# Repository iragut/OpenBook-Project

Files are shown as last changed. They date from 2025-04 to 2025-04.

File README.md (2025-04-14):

# README - OpenBook E-Reader

## Introducere
OpenBook este un e-reader open-source construit în jurul microcontrollerului ESP32-C6, integrând un display e-paper de 7.5 inch, senzori de mediu (BME680), management al bateriei și interfețe precum Wi-Fi și USB-C. Acest document oferă o privire de ansamblu asupra designului hardware, componentelor utilizate și conexiunilor lor.

---

## Diagrama bloc
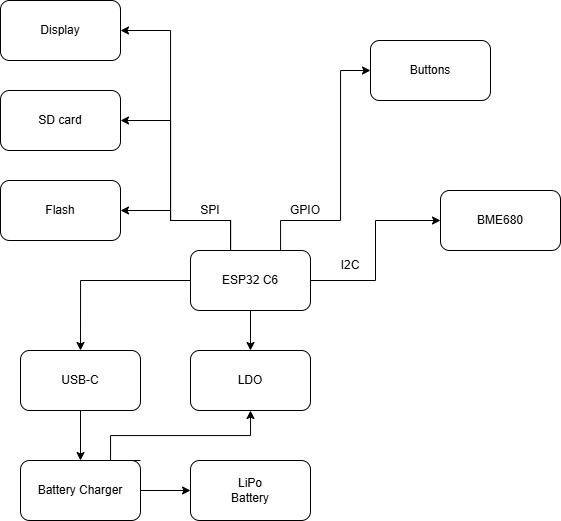
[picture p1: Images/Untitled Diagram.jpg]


## Bill of Materials (BOM)
Tabelul de mai jos include componentele principale din BOM-ul furnizat, cu link-uri către Mouser și datasheet-uri unde sunt disponibile.

| **Componentă** | **Valoare/Part Number** | **Descriere** | **Furnizor (Mouser)** | **Datasheet** |
|---|---|---|---|---|
| U2 | ESP32-C6-WROOM-1-N8 | Microcontroller Wi-Fi 6, Bluetooth 5 | [Mouser](https://eu.mouser.com/ProductDetail/Espressif-Systems/ESP32-C6-WROOM-1-N8)  | [Datasheet](https://www.espressif.com/sites/default/files/documentation/esp32-c6-wroom-1_datasheet_en.pdf) |
| U1 | W25Q512JVEIQ | 512Mb Flash SPI | [Mouser](https://eu.mouser.com/ProductDetail/Winbond/W25Q512JVEIQ) | [Datasheet](https://www.winbond.com/resource-files/W25Q512JV%20RevD%2004082020.pdf) |
| S | BME680 | Senzor temperatură, umiditate, presiune | [Mouser](https://eu.mouser.com/ProductDetail/Bosch-Sensortec/BME680) | [Datasheet](https://www.bosch-sensortec.com/media/boschsensortec/downloads/datasheets/bst-bme680-ds001.pdf) |
| U3 | DS3231SN# | RTC I2C | [Mouser](https://eu.mouser.com/ProductDetail/Analog-Devices/DS3231SN) | [Datasheet](https://www.analog.com/media/en/technical-documentation/data-sheets/DS3231.pdf) |
| U4 | MAX17048G+T10 | Fuel Gauge I2C | [Mouser](https://eu.mouser.com/ProductDetail/Analog-Devices/MAX17048G+T10) | [Datasheet](https://www.analog.com/media/en/technical-documentation/data-sheets/MAX17048.pdf) |
| U5 | MCP73831T-2ACI/OT | Încărcător Li-Po USB-C | [Mouser](https://eu.mouser.com/ProductDetail/Microchip-Technology/MCP73831T-2ACI-OT) | [Datasheet](https://ww1.microchip.com/downloads/en/DeviceDoc/20001984G.pdf) |
| J2 | USB4110-GF-A | Conector USB-C | [Mouser](https://eu.mouser.com/ProductDetail/GCT/USB4110-GF-A) | [Datasheet](https://www.gct.co/connector/usb4110) |
| BOOT_BUTTON | EVQPUJ02K | Buton tactil | [Mouser](https://eu.mouser.com/ProductDetail/Panasonic/EVQ-PUJ02K) | [Datasheet](https://www.panasonic.com/global/industrial-components/switches/light-touch/evqpuj02k.pdf) |
| C3 | 100uF TANT (F910J107MBAAJ6) | Condensator polarizat | [Mouser](https://eu.mouser.com/ProductDetail/KYOCERA-AVX/F910J107MBAAJ6) | [Datasheet](https://www.kyocera-avx.com/products/tantalum/) |
| IC4 | XC6220A331MR-G | LDO Regulator | [Mouser](https://eu.mouser.com/ProductDetail/Torex/XC6220A331MR-G) | [Datasheet](https://www.torexsemi.com/file/xc6220/XC6220.pdf) |

---

## Funcționalitate Hardware

### Microcontroller ESP32-C6-WROOM-1-N8
- **Rol**: Procesare centrală, conectivitate Wi-Fi 6 și Bluetooth 5, control al perifericelor.
- **Interfețe**:
  - SPI: Display e-paper, Flash (W25Q512JVEIQ), Micro SD.
  - I2C: BME680, MAX17048, DS3231.
  - GPIO: Butoane, LED, pini de control display.
  - UART: Debugging și extensii.
- **Specificații**: 160MHz, 512KB SRAM, 8MB Flash integrat.

### Display E-Paper
- **Specificații**: 7.5 inch, 800x480, contrast 8:1, SPI 4-wire.
- **Conexiune**: MOSI, MISO, SCK, CS + DC, RST, BUSY.
- **Consum**: <50mA în refresh, aproape 0 în standby.

### Senzor BME680
- **Funcție**: Măsoară temperatura (±1°C), umiditatea (±3%), presiunea (±1 hPa) și calitatea aerului (eCO2, TVOC).
- **Interfață**: I2C la 400kHz.
- **Consum**: <1mA activ, <1µA în sleep.

### Management Baterie
- **Baterie**: 2500mAh Li-Po, 3.7V.
- **Încărcare**: MCP73831 prin USB-C (1A max).
- **Monitorizare**: MAX17048 prin I2C.
- **Consum**: <50µA în deep sleep.

### Butoane
- Trei butoane tactile (Panasonic EVQPUJ02K) pentru navigare, cu rezistențe pull-up de 10K.

### USB-C
- **Rol**: Încărcare (5V/1A) și transfer date (USB 2.0).
- **Protecție**: ESD diodes (USBLC6-2SC6Y).

### Calcul Consum Energie
- **Activ (Wi-Fi + Display Refresh)**: ~150mA.
- **Citire (Display static)**: ~10mA.
- **Deep Sleep**: <50µA.
- **Autonomie estimată**: ~1 săptămână (2500mAh / 10mA medie = ~250 ore).

---

## Pini ESP32-C6 Utilizați

| **Pin ESP32-C6** | **Funcție** | **Componentă** | **Motiv** |
|---|---|---|---|
| GPIO0 | BOOT_BUTTON | Buton | Detectare mod boot la pornire |
| GPIO1 | RESET_BUTTON | Buton | Reset manual al dispozitivului |
| GPIO2 | CHANGE_BUTTON | Buton | Navigare meniuri |
| GPIO3 | EPD_CS | Display E-Paper | Chip Select pentru SPI |
| GPIO4 | EPD_DC | Display E-Paper | Data/Command control |
| GPIO5 | EPD_RST | Display E-Paper | Reset display |
| GPIO6 | EPD_BUSY | Display E-Paper | Detectare stare refresh |
| GPIO7 | SPI_MOSI | Display, Flash, SD | Master Out Slave In (SPI) |
| GPIO8 | SPI_MISO | Display, Flash, SD | Master In Slave Out (SPI) |
| GPIO9 | SPI_SCK | Display, Flash, SD | Clock SPI |
| GPIO10 | FLASH_CS | W25Q512JVEIQ | Chip Select pentru Flash |
| GPIO11 | SD_CS | Micro SD | Chip Select pentru SD |
| GPIO12 | I2C_SDA | BME680, MAX17048, DS3231 | Date I2C |
| GPIO13 | I2C_SCL | BME680, MAX17048, DS3231 | Clock I2C |
| GPIO14 | CHG_LED | LED | Indicare status încărcare |
| GPIO15 | UART_TX | Debugging | Transmitere date serial |
| GPIO16 | UART_RX | Debugging | Recepție date serial |
| GPIO17 | USB_D+ | USB-C | Linie date USB pozitivă |
| GPIO18 | USB_D- | USB-C | Linie date USB negativă |

**Notă**: Pinii sunt alocați conform specificațiilor ESP32-C6 și cerințelor ERD/PRD. Unii pini pot fi multifuncționali (ex. GPIO/SPI).

---

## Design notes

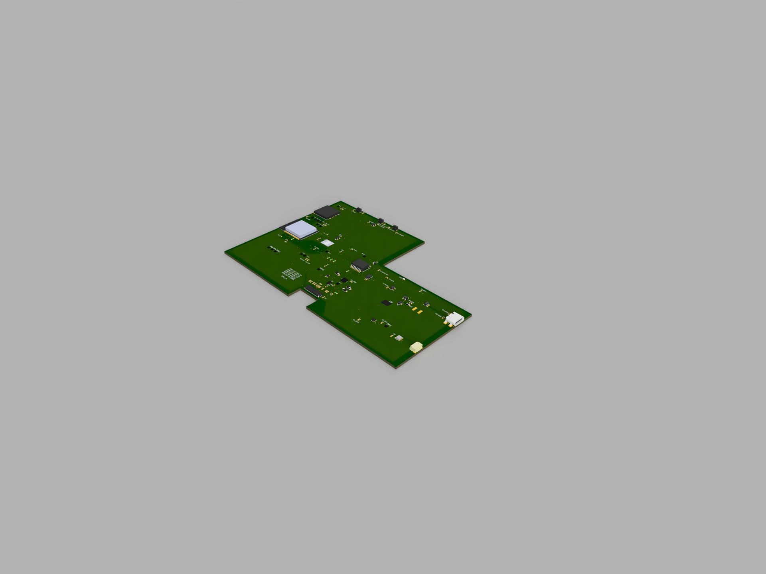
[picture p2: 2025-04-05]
Images/pcb.JPEG

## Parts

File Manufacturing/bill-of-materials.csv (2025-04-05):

Qty | Value | Device | Package | Parts | Description | ARROW_PART_NUMBER | ARROW_PRICE-STOCK | AVAILABILITY | CENTROID_NOT_SPECIFIED | CHECK_PRICES | COPYRIGHT | DATASHEET | DESCRIPTION | DIGIKEY_DESCRIPTION | DIGIKEY_PART_NUMBER | HEIGHT | LEAD_FREE | MANUFACTURER_NAME | MANUFACTURER_PART_NUMBER | MF | MFR_NAME | MOUSER_PART_NUMBER | MOUSER_PRICE-STOCK | MOUSER_TESTING_PART_NUMBER | MOUSER_TESTING_PRICE-STOCK | MP | MPN | PACKAGE | POPULARITY | PREFIX | PRICE | PROD_ID | PURCHASE-URL | ROHS | SNAPEDA_LINK | SPICEMODEL | SPICEPREFIX | TEMPERATURE_RANGE_HIGH | TEMPERATURE_RANGE_LOW | TP_SIGNAL_NAME | VALUE
1 |  | ADAFRUIT_LEDCHIP-LED0603 | ADAFRUIT_CHIP-LED0603 | LED1 | LED
1 |  | SJ | SJ | SJ1 | SMD solder JUMPER |  |  |  |  |  |  |  |  |  |  |  |  |  |  |  |  |  |  |  |  |  |  |  | 3
1 | 0.1uF/50V | ESP32_WROVER_EAGLE-LTSPICE_CC0402 | ESP32_WROVER_EAGLE-LTSPICE_C0402 | EPD_C5 | CAPACITOR, European symbol |  |  |  |  |  |  |  |  |  |  |  |  |  |  |  |  |  |  |  |  |  |  |  |  |  |  |  |  |  |  | NONE | C
1 | 0.47 | ESP32_WROVER_EAGLE-LTSPICE_RR0402 | ESP32_WROVER_EAGLE-LTSPICE_R0402 | R6 | RESISTOR, European symbol |  |  |  |  |  |  |  |  |  |  |  |  |  |  |  |  |  |  |  |  |  |  |  |  |  |  |  |  |  |  | NONE | R
1 | 100k | ESP32_WROVER_EAGLE-LTSPICE_RR0402 | ESP32_WROVER_EAGLE-LTSPICE_R0402 | R1 | RESISTOR, European symbol |  |  |  |  |  |  |  |  |  |  |  |  |  |  |  |  |  |  |  |  |  |  |  |  |  |  |  |  |  |  | NONE | R
8 | 100nF | ESP32_WROVER_EAGLE-LTSPICE_CC0402 | ESP32_WROVER_EAGLE-LTSPICE_C0402 | C1, C2, C4_USB, C5_USB2, C8, COND_BOOT, COND_CHANGE, C_DELAY | CAPACITOR, European symbol |  |  |  |  |  |  |  |  |  |  |  |  |  |  |  |  |  |  |  |  |  |  |  |  |  |  |  |  |  |  | NONE | C
1 | 100uF TANT | RCL_CPOL-EUCT3528 | RCL_CT3528 | C3 | POLARIZED CAPACITOR, European symbol |  |  |  |  |  |  |  |  |  |  |  |  |  |  |  |  |  |  |  |  |  |  |  | 0 |  |  |  |  |  |  |  | C
15 | 10K | ESP32_WROVER_EAGLE-LTSPICE_RR0402 | ESP32_WROVER_EAGLE-LTSPICE_R0402 | R1_PINH1, R2_PINH1, R5, R8, R9, R10, R11, R12, R13, R14, R15, R16, R_BOOT, R_CHANGE, R_RESET | RESISTOR, European symbol |  |  |  |  |  |  |  |  |  |  |  |  |  |  |  |  |  |  |  |  |  |  |  |  |  |  |  |  |  |  | NONE | R
1 | 10k | ESP32_WROVER_EAGLE-LTSPICE_RR0402 | ESP32_WROVER_EAGLE-LTSPICE_R0402 | R7 | RESISTOR, European symbol |  |  |  |  |  |  |  |  |  |  |  |  |  |  |  |  |  |  |  |  |  |  |  |  |  |  |  |  |  |  | NONE | R
1 | 112A-TAAR-R03_ATTEND | 112A-TAAR-R03_ATTEND | 112ATAARR03ATTEND | J2 | Micro SD Card Socket, Push-Push Type, Top Mount, SMT, H=1.83mm, 10u |  |  |  |  |  |  |  | Micro SD Card Socket | Push-Push Type | Top Mount | SMT | H=1.83mm | 10u |  |  | 1.9mm |  | ATTEND | 112A-TAAR-R03 ATTEND
1 | 15 | ESP32_WROVER_EAGLE-LTSPICE_RR0402 | ESP32_WROVER_EAGLE-LTSPICE_R0402 | R_CAPACITOR | RESISTOR, European symbol |  |  |  |  |  |  |  |  |  |  |  |  |  |  |  |  |  |  |  |  |  |  |  |  |  |  |  |  |  |  | NONE | R
1 | 1uF | ESP32_WROVER_EAGLE-LTSPICE_CC0402 | ESP32_WROVER_EAGLE-LTSPICE_C0402 | COND_RESET | CAPACITOR, European symbol |  |  |  |  |  |  |  |  |  |  |  |  |  |  |  |  |  |  |  |  |  |  |  |  |  |  |  |  |  |  | NONE | C
9 | 1uF/50V | ESP32_WROVER_EAGLE-LTSPICE_CC0402 | ESP32_WROVER_EAGLE-LTSPICE_C0402 | EPD_C1, EPD_C2, EPD_C6, EPD_C7, EPD_C8, EPD_C9, EPD_C10, EPD_C11, EPD_C12 | CAPACITOR, European symbol |  |  |  |  |  |  |  |  |  |  |  |  |  |  |  |  |  |  |  |  |  |  |  |  |  |  |  |  |  |  | NONE | C
1 | 2.2 | ESP32_WROVER_EAGLE-LTSPICE_RR0402 | ESP32_WROVER_EAGLE-LTSPICE_R0402 | R4 | RESISTOR, European symbol |  |  |  |  |  |  |  |  |  |  |  |  |  |  |  |  |  |  |  |  |  |  |  |  |  |  |  |  |  |  | NONE | R
1 | 200 | ESP32_WROVER_EAGLE-LTSPICE_RR0402 | ESP32_WROVER_EAGLE-LTSPICE_R0402 | R1_BAT | RESISTOR, European symbol |  |  |  |  |  |  |  |  |  |  |  |  |  |  |  |  |  |  |  |  |  |  |  |  |  |  |  |  |  |  | NONE | R
2 | 20V/4.2A/52mO/1.4W | ESP32_WROVER_SPARKFUN-DISCRETESEMI_MOSFET_PCH-DMG2305UX-7 | ESP32_WROVER_SPARKFUN-DISCRETESEMI_SOT23-3 | Q1, Q3 | P-channel MOSFETs |  |  |  |  |  |  |  |  |  |  |  |  |  |  |  |  |  |  |  |  |  |  |  |  |  |  | TRAN-14388 |  |  |  |  |  |  |  |  | 20V/4.2A/52mO/1.4W
1 | 2k | ESP32_WROVER_EAGLE-LTSPICE_RR0402 | ESP32_WROVER_EAGLE-LTSPICE_R0402 | R2_BAT | RESISTOR, European symbol |  |  |  |  |  |  |  |  |  |  |  |  |  |  |  |  |  |  |  |  |  |  |  |  |  |  |  |  |  |  | NONE | R
7 | 4.7uF | ESP32_WROVER_EAGLE-LTSPICE_CC0402 | ESP32_WROVER_EAGLE-LTSPICE_C0402 | C1_BAT, C1_BAT1, C1_BAT2, C2_BAT, C5_USB, C5_USB3, C5_USB4 | CAPACITOR, European symbol |  |  |  |  |  |  |  |  |  |  |  |  |  |  |  |  |  |  |  |  |  |  |  |  |  |  |  |  |  |  | NONE | C
2 | 5k1 | ESP32_WROVER_EAGLE-LTSPICE_RR0402 | ESP32_WROVER_EAGLE-LTSPICE_R0402 | R2-USB1, R2-USB2 | RESISTOR, European symbol |  |  |  |  |  |  |  |  |  |  |  |  |  |  |  |  |  |  |  |  |  |  |  |  |  |  |  |  |  |  | NONE | R
1 | 68uH | 744043680IND_4828-WE-TPC_WRE | IND_4828-WE-TPC_WRE | L1 |  |  |  |  |  |  | Copyright (C) 2024 Ultra Librarian. All rights reserved. |  |  |  |  |  |  |  | 744043680 |  | Wurth Electronics
1 | BD5229G-TR | BD5229G-TR | SOT95P280X125-5N | IC3 | Voltage Detector with Adjustable Delay Time: CMOS processes are utilized to develop high precision, low current consumption CMOS reset ICs that allow arbitrary setting of the delay time. The extensive lineup includes both Nch Open Drain and CMOS output types in a wide range of detection voltages (from 2.3V to 6.0V, in 0.1V steps), enabling selection of the ideal solution based on customer requirements. In addition, the entire series is of course both lead-free and RoHS-compliant. |  |  |  |  |  |  |  | Voltage Detector with Adjustable Delay Time: CMOS processes are utilized to develop high precision | low current consumption CMOS reset ICs that allow arbitrary setting of the delay time. The extensive lineup includes both Nch Open Drain and CMOS output types in a wide range of detection voltages (from 2.3V to 6.0V | in 0.1V steps) | enabling selection of the ideal solution based on customer requirements. In addition | the entire series is of course both lead-free and RoHS-compliant. |  |  | 1.25mm |  | ROHM Semiconductor | BD5229G-TR |  |  | 755-BD5229G-TR | https://www.mouser.co.uk/ProductDetail/ROHM-Semiconductor/BD5229G-TR?qs=4kLU8WoGk0vvnhrrYwdszw%3D%3D
1 | BME680 | ESP32_WROVER_BME680_BME680 | ESP32_WROVER_BME680_PSON80P300X300X100-8N | U3 | Integrated Environmental Unit |  |  | Unavailable |  |  |  |  | Integrated Environmental Unit |  |  |  |  |  |  | Bosch Sensortec |  |  |  |  |  | BME680 |  | LGA-8 Bosch Tools |  |  | None
2 | BUTTON_CUSYOMV1 | BUTTON_CUSYOMV1 | MYBUTTON | BOOT_BUTTON, RESET_BUTTON
1 | CHANGE_BUTTON | BUTTON_CUSYOMV1 | MYBUTTON | CHANGE_BUTTON
1 | CPH3225A | CPH3225A | CAPCP3225X100N | C7 | Cap 0.011F 3.3V 1210 Flat Check availability |  |  | Not in stock |  | https://www.snapeda.com/parts/CPH3225A/Seiko+Instruments/view-part/?ref=eda |  |  | 11 mF (EDLC) Supercapacitor 3.3 V 1210 (3225 Metric) - - |  |  |  |  |  |  | Seiko Instruments |  |  |  |  |  | CPH3225A |  | 1210 Seiko |  |  | None |  | https://www.snapeda.com/api/url_track_click_mouser/?unipart_id=562593&manufacturer=Seiko Instruments&part_name=CPH3225A&search_term=None |  | https://www.snapeda.com/parts/CPH3225A/Seiko+Instruments/view-part/?ref=snap
1 | DS3231SN# | DS3231SN# | SOIC127P1032X265-16N | U5 | Real Time Clock Serial 16-Pin SOIC W T/R Check availability |  |  | In Stock |  | https://www.snapeda.com/parts/DS3231SN%23/Analog+Devices/view-part/?ref=eda |  |  | Extremely Accurate I²C-Integrated RTC/TCXO/Crystal |  |  |  |  |  |  | Analog Devices |  |  |  |  |  | DS3231SN# |  | SOIC-16 Maxim |  |  | None |  | https://www.snapeda.com/api/url_track_click_mouser/?unipart_id=99048&manufacturer=Analog Devices&part_name=DS3231SN#&search_term=None |  | https://www.snapeda.com/parts/DS3231SN%23/Analog+Devices/view-part/?ref=snap
1 | ESP32-C6-WROOM-1-N8 | ESP32-C6-WROOM-1-N8 | XCVR_ESP32-C6-WROOM-1-N8 | U2 | Check availability |  |  | In Stock |  | https://www.snapeda.com/parts/ESP32-C6-WROOM-1-N8/Espressif+Systems/view-part/?ref=eda |  |  | Multiprotocol Modules ESP32-C6 module | Wi-Fi 6 in 2.4 GHz band | Bluetooth 5 | Zigbee 3.0 and Thread. ESP34-WROOM Compatible - ENGINEERING SAMPLE |  |  |  |  |  |  | Espressif Systems |  |  |  |  |  | ESP32-C6-WROOM-1-N8 |  | None |  |  | None |  |  |  | https://www.snapeda.com/parts/ESP32-C6-WROOM-1-N8/Espressif+Systems/view-part/?ref=snap
1 | ESP32C6_VARISTORCN1812 | ESP32C6_VARISTORCN1812 | ESP32C6_VARISTOR_CT/CN1812 | PFMF.050.1 | VARISTOR |  |  |  |  |  |  |  |  |  |  |  |  |  |  |  |  |  |  |  |  |  |  |  | 0
2 | ESP32_WROVER_AVX---SD0805S020S1R0_AVX_SD0805S020S1R0_0_0AVX_SD0805S020S1R0_0_0 | ESP32_WROVER_AVX---SD0805S020S1R0_AVX_SD0805S020S1R0_0_0AVX_SD0805S020S1R0_0_0 | ESP32_WROVER_AVX---SD0805S020S1R0_AVX_SD0805S020S1R0_0 | D2, D6 | Schottky Barrier Rectifier Diode |  |  |  | No |  |  | http://datasheets.avx.com/schottky.pdf |  | DIODE SCHOTTKY 20V 1A 0805 | 478-7800-1-ND |  | yes |  |  | AVX |  | 581-SD0805S020S1R0 |  |  |  |  |  | 0805 (2012 metric) |  | D |  |  |  | yes |  |  |  | +125°C | -55°C
1 | FH34SRJ-24S-0.5SH_99_ | FH34SRJ-24S-0.5SH_99_ | FH34SRJ24S05SH99 | J3 | (0.50mm) Surface Mount, Right Angle |  |  |  |  |  |  |  | 24 Position FFC | FPC Connector Contacts | (0.50mm) Surface Mount | Right Angle |  |  | 1.1mm |  | Hirose | FH34SRJ-24S-0.5SH(99) |  |  | 798-FH34SRJ24S05SH99 | https://www.mouser.co.uk/ProductDetail/Hirose-Connector/FH34SRJ-24S-0.5SH99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
1 | MAX17048G+T10 | MAX17048G+T10 | SON50P200X200X80-9N | U4 | Check availability |  |  | In Stock |  | https://www.snapeda.com/parts/MAX17048G+T10/Analog+Devices/view-part/?ref=eda |  |  | 3µA 1-Cell/2-Cell Fuel Gauge with ModelGauge |  |  |  |  |  |  | Analog Devices |  |  |  |  |  | MAX17048G+T10 |  | TDFN-8 Maxim |  |  | None |  | https://www.snapeda.com/api/url_track_click_mouser/?unipart_id=329239&manufacturer=Analog Devices&part_name=MAX17048G+T10&search_term=None |  | https://www.snapeda.com/parts/MAX17048G+T10/Analog+Devices/view-part/?ref=snap
3 | MBR0530 | MBR0530 | SOD3716X135N | D3, D4, D5 | ON SEMICONDUCTOR - MBR0530 - DIODE, SCHOTTKY, 0.5A, 30V, SOD-123 |  |  | In Stock |  | https://www.snapeda.com/parts/MBR0530/Onsemi/view-part/?ref=eda |  |  | Diode Schottky 30 V 500mA Surface Mount SOD-123 |  |  |  |  |  |  | ON Semiconductor |  |  |  |  |  | MBR0530 |  | SOD-123-2 ON Semiconductor |  |  | None |  | https://www.snapeda.com/api/url_track_click_mouser/?unipart_id=179458&manufacturer=ON Semiconductor&part_name=MBR0530&search_term=None |  | https://www.snapeda.com/parts/MBR0530/Onsemi/view-part/?ref=snap
1 | MCP73831 | ESP32_WROVER_SPARKFUN-IC-POWER_MCP73831 | ESP32_WROVER_SPARKFUN-IC-POWER_SOT23-5 | U1 | MCP73831T Li-Ion, Li-Pol Controller |  |  |  |  |  |  |  |  |  |  |  |  |  |  |  |  |  |  |  |  |  |  |  |  |  |  | IC-09995
6 | PGB1010603MR | PGB1010603MR | DIOC1608X36N | D7, D8, D9, D10, D11, D12 | Check availability |  |  | In Stock |  | https://www.snapeda.com/parts/PGB1010603MR/Littelfuse/view-part/?ref=eda |  |  | 150V (Typ) Clamp - Ipp Tvs Diode Surface Mount 0603 (1608 Metric) |  |  |  |  |  |  | Littelfuse Inc. |  |  |  |  |  | PGB1010603MR |  | 0603 Littelfuse Inc. |  |  | None |  | https://www.snapeda.com/api/url_track_click_mouser/?unipart_id=5659453&manufacturer=Littelfuse Inc.&part_name=PGB1010603MR&search_term=None |  | https://www.snapeda.com/parts/PGB1010603MR/Littelfuse/view-part/?ref=snap
1 | QWIIC_RIGHT_ANGLE | QWIIC_CONNECTOR | JST04_1MM_RA | J4 | SparkFun I2C Standard Qwiic Connector
1 | SAMACSYS_PARTS_USB4110-GF-A | SAMACSYS_PARTS_USB4110-GF-A | SAMACSYS_PARTS_USB4110GFA | J1 | CONN USB 2.0 TYPE-C R/A SMT |  |  |  |  |  |  |  | CONN USB 2.0 TYPE-C R/A SMT |  |  | 3.26mm |  | GCT (GLOBAL CONNECTOR TECHNOLOGY) | USB4110-GF-A |  |  | 640-USB4110-GF-A | https://www.mouser.co.uk/ProductDetail/GCT/USB4110-GF-A?qs=KUoIvG%2F9IlYiZvIXQjyJeA%3D%3D
1 | SI1308EDL-T1-GE3 | SI1308EDL-T1-GE3 | SOT65P210X110-3N | Q2 | MOSFET N-Ch 30V 1.5A TrenchFET SC70 Vishay Si1308EDL-T1-GE3 N-channel MOSFET Transistor, 1.5 A, 30 V, 3-Pin SC-70 |  |  | In Stock |  | https://www.snapeda.com/parts/SI1308EDL-T1-GE3/Vishay+Siliconix/view-part/?ref=eda |  |  | Si1308EDL-T1-GE3 N-channel MOSFET Transistor | 1.5 A | 30 V | 3-Pin SC-70 | Siliconix / Vishay SI1308EDL-T1-GE3 |  |  |  |  |  |  | Vishay Siliconix |  |  |  |  |  | SI1308EDL-T1-GE3 |  | SOT-323 Vishay Semiconductor |  |  | None |  | https://www.snapeda.com/api/url_track_click_mouser/?unipart_id=274603&manufacturer=Vishay Siliconix&part_name=SI1308EDL-T1-GE3&search_term=None |  | https://www.snapeda.com/parts/SI1308EDL-T1-GE3/Vishay+Siliconix/view-part/?ref=snap
17 | TPTP20R | TPTP20R | TP20R | TP1, TP2, TP3, TP4, TP5, TP6, TP7, TP8, TP9, TP10, TP11, TP12, TP13, TP14, TP15, TP16, TP17 | Test pad |  |  |  |  |  |  |  |  |  |  |  |  |  |  |  |  |  |  |  |  |  |  |  | 2
1 | USBLC6-2SC6Y | USBLC6-2SC6Y | SOT95P280X145-6N | D1 | Low Cap. ESD Protection Auto SOT-23-6 STMicroelectronics USBLC6-2SC6Y, Dual Uni-Directional TVS Diode Array, 6-Pin SOT-23 |  |  | In Stock |  | https://www.snapeda.com/parts/USBLC6-2SC6Y/STMicroelectronics/view-part/?ref=eda |  |  | 17V Clamp 5A (8/20µs) Ipp Tvs Diode Surface Mount SOT-23-6 |  |  |  |  |  |  | STMicroelectronics |  |  |  |  |  | USBLC6-2SC6Y |  | SOT-23-6 STMicroelectronics |  |  | None |  |  |  | https://www.snapeda.com/parts/USBLC6-2SC6Y/STMicroelectronics/view-part/?ref=snap
1 | W25Q512JVEIQ | W25Q512JVEIQ | SON127P600X800X80-9N | U6 | Check availability |  |  | In Stock |  | https://www.snapeda.com/parts/W25Q512JVEIQ/Winbond+Electronics/view-part/?ref=eda |  |  | FLASH - NOR Memory IC 512Mb (64M x 8) SPI - Quad I/O 133 MHz 8-WSON (8x6) |  |  |  |  |  |  | Winbond Electronics |  |  |  |  |  | W25Q512JVEIQ |  | Package |  |  | None |  |  |  | https://www.snapeda.com/parts/W25Q512JVEIQ/Winbond+Electronics/view-part/?ref=snap
1 | XC6220A331MR-G | XC6220A331MR-G | SOT95P280X120-5N | IC1 | LDO Voltage Regulators

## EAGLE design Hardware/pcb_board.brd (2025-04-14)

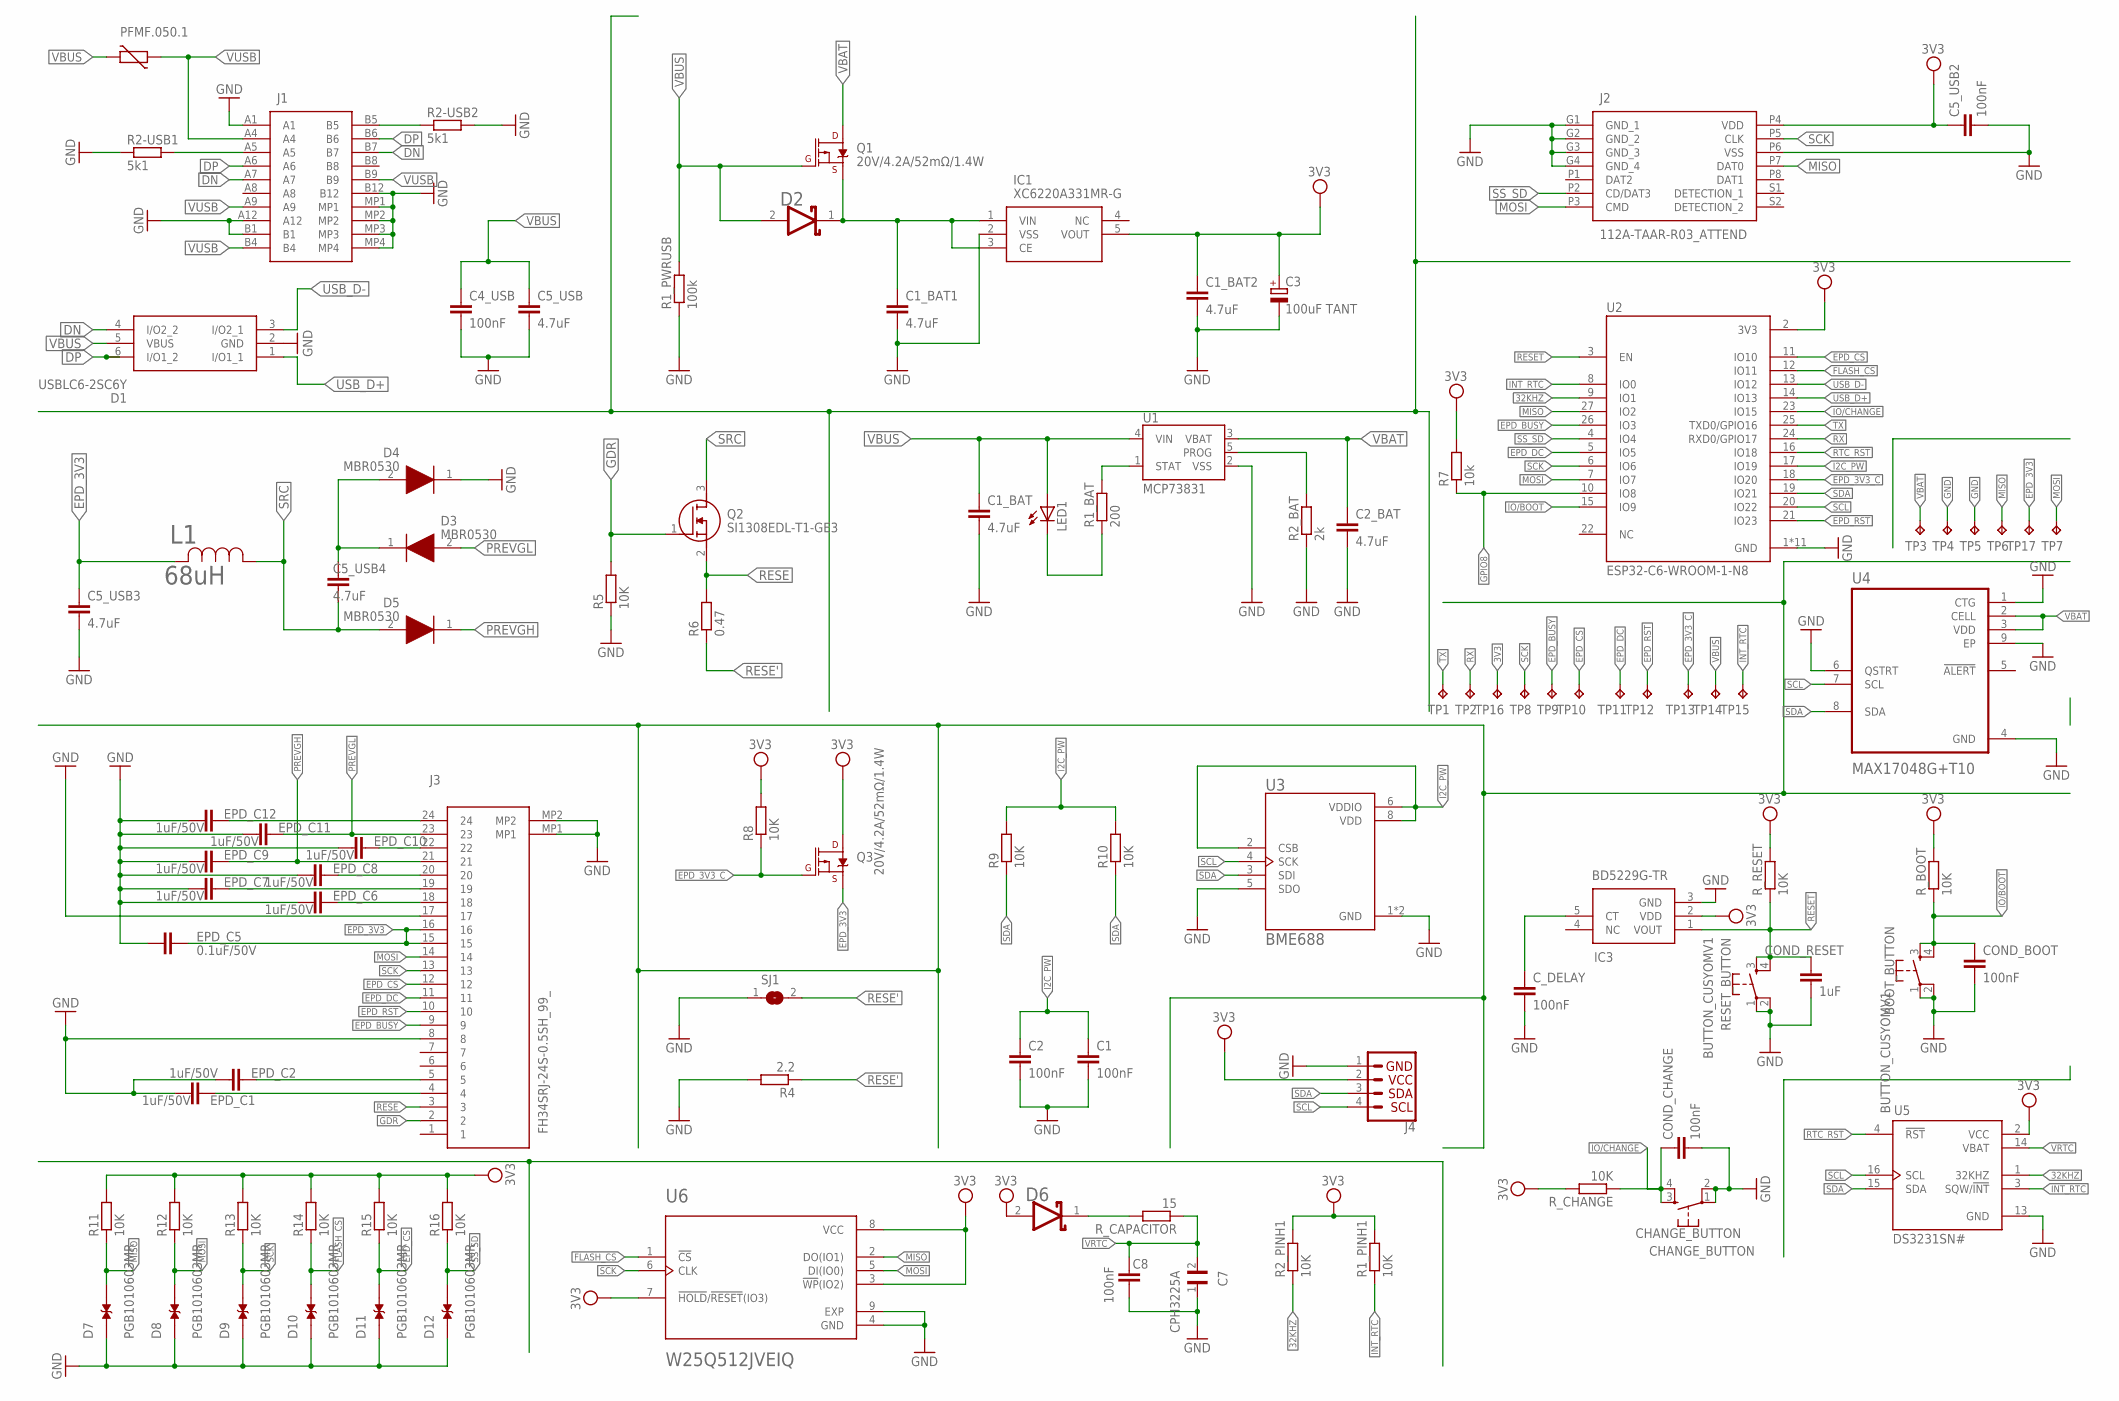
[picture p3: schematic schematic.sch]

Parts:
BOOT_BUTTON: BUTTON_CUSYOMV1; MYBUTTON
C1, C2, C4_USB, C5_USB2, C8: 100nF; ESP32_WROVER_EAGLE-LTSPICE_C0402
C1_BAT, C1_BAT1, C1_BAT2, C2_BAT, C5_USB, C5_USB3, C5_USB4: 4.7uF; ESP32_WROVER_EAGLE-LTSPICE_C0402
C3: 100uF TANT; RCL_CT3528
C7: CPH3225A; CAPCP3225X100N
CHANGE_BUTTON: CHANGE_BUTTON; MYBUTTON
COND_BOOT: 100nF; ESP32_WROVER_EAGLE-LTSPICE_C0402
COND_CHANGE: 100nF; ESP32_WROVER_EAGLE-LTSPICE_C0402
COND_RESET: 1uF; ESP32_WROVER_EAGLE-LTSPICE_C0402
C_DELAY: 100nF; ESP32_WROVER_EAGLE-LTSPICE_C0402
D1: USBLC6-2SC6Y; SOT95P280X145-6N
D2: SD0805S020S1R0; ESP32_WROVER_AVX---SD0805S020S1R0_AVX_SD0805S020S1R0_0
D3, D4, D5: MBR0530; SOD3716X135N
D6: ESP32_WROVER_AVX---SD0805S020S1R0_AVX_SD0805S020S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; ESP32_WROVER_AVX---SD0805S020S1R0_AVX_SD0805S020S1R0_0
D7, D8, D9, D10, D11, D12: PGB1010603MR; DIOC1608X36N
EPD_C1, EPD_C2, EPD_C6, EPD_C7, EPD_C8, EPD_C9, EPD_C10, EPD_C11, EPD_C12: 1uF/50V; ESP32_WROVER_EAGLE-LTSPICE_C0402
EPD_C5: 0.1uF/50V; ESP32_WROVER_EAGLE-LTSPICE_C0402
IC1: XC6220A331MR-G; SOT95P280X120-5N
IC3: BD5229G-TR; SOT95P280X125-5N
J1: SAMACSYS_PARTS_USB4110-GF-A; SAMACSYS_PARTS_USB4110GFA
J2: 112A-TAAR-R03_ATTEND; 112ATAARR03ATTEND
J3: FH34SRJ-24S-0.5SH_99_; FH34SRJ24S05SH99
J4: QWIIC_RIGHT_ANGLE; JST04_1MM_RA
L1: 68uH; IND_4828-WE-TPC_WRE
LED1: ADAFRUIT_LEDCHIP-LED0603; ADAFRUIT_CHIP-LED0603
PFMF.050.1: ESP32C6_VARISTORCN1812; ESP32C6_VARISTOR_CT/CN1812
Q1, Q3: 20V/4.2A/52mΩ/1.4W; ESP32_WROVER_SPARKFUN-DISCRETESEMI_SOT23-3
Q2: SI1308EDL-T1-GE3; SOT65P210X110-3N
R1_BAT: 200; ESP32_WROVER_EAGLE-LTSPICE_R0402
R1_PINH1, R2_PINH1, R5, R8, R9, R10, R11, R12, R13, R14, R15, R16: 10K; ESP32_WROVER_EAGLE-LTSPICE_R0402
R1_PWRUSB: 100k; ESP32_WROVER_EAGLE-LTSPICE_R0402
R2-USB1, R2-USB2: 5k1; ESP32_WROVER_EAGLE-LTSPICE_R0402
R2_BAT: 2k; ESP32_WROVER_EAGLE-LTSPICE_R0402
R4: 2.2; ESP32_WROVER_EAGLE-LTSPICE_R0402
R6: 0.47; ESP32_WROVER_EAGLE-LTSPICE_R0402
R7: 10k; ESP32_WROVER_EAGLE-LTSPICE_R0402
RESET_BUTTON: BUTTON_CUSYOMV1; MYBUTTON
R_BOOT: 10K; ESP32_WROVER_EAGLE-LTSPICE_R0402
R_CAPACITOR: 15; ESP32_WROVER_EAGLE-LTSPICE_R0402
R_CHANGE: 10K; ESP32_WROVER_EAGLE-LTSPICE_R0402
R_RESET: 10K; ESP32_WROVER_EAGLE-LTSPICE_R0402
SJ1: SJ
TP1, TP2, TP3, TP4, TP5, TP6, TP7, TP8, TP9, TP10, TP11, TP12, TP13, TP14, TP15, TP16, TP17: TPTP20R; TP20R
U1: MCP73831; ESP32_WROVER_SPARKFUN-IC-POWER_SOT23-5
U2: ESP32-C6-WROOM-1-N8; XCVR_ESP32-C6-WROOM-1-N8
U3: BME688; ESP32_WROVER_BME680_PSON80P300X300X100-8N
U4: MAX17048G+T10; SON50P200X200X80-9N
U5: DS3231SN#; SOIC127P1032X265-16N
U6: W25Q512JVEIQ; SON127P600X800X80-9N

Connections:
3V3: C1_BAT2.1, C3.+, C5_USB2.1, D6.2 (ANODE), IC1.5 (VOUT), IC3.2 (VDD), J2.P4 (VDD), J4.2, Q3.3 (D), R1_PINH1.2, R2_PINH1.2, R7.2, R8.2, R11.2, R12.2, R13.2, R14.2, R15.2, R16.2, R_BOOT.2, R_CHANGE.2, R_RESET.2, TP16.TP, U2.2 (3V3), U5.2 (VCC), U6.3 (!WP!(IO2)), U6.7 (!HOLD!/!RESET!(IO3)), U6.8 (VCC)
32KHZ: R2_PINH1.1, U2.9 (IO1), U5.1 (32KHZ)
DN: D1.4 (I/O2_2), J1.A7, J1.B7
DP: D1.6 (I/O1_2), J1.A6, J1.B6
EPD_3V3: C5_USB3.1, EPD_C5.1, J3.15, J3.16, L1.2, Q3.2 (S), TP17.TP
EPD_3V3_C: Q3.1 (G), R8.1, TP13.TP, U2.18 (IO20)
EPD_BUSY: J3.9, TP9.TP, U2.26 (IO3)
EPD_CS: D11.2, J3.12, R15.1, TP10.TP, U2.11 (IO10)
EPD_DC: J3.11, TP11.TP, U2.5 (IO5)
EPD_RST: J3.10, TP12.TP, U2.21 (IO23)
FLASH_CS: D10.2, R14.1, U2.12 (IO11), U6.1 (!CS)
GDR: J3.2, Q2.1 (G), R5.2
GND: BOOT_BUTTON.1, BOOT_BUTTON.2, C1.2, C1_BAT.2, C1_BAT1.2, C1_BAT2.2, C2.2, C2_BAT.2, C3.-, C4_USB.2, C5_USB.2, C5_USB2.2, C5_USB3.2, C7.1, C8.2, CHANGE_BUTTON.1, CHANGE_BUTTON.2, COND_BOOT.2, COND_CHANGE.2, COND_RESET.2, C_DELAY.2, D1.2 (GND), D4.1 (K), D7.1, D8.1, D9.1, D10.1, D11.1, D12.1, EPD_C1.2, EPD_C2.2, EPD_C5.2, EPD_C6.2, EPD_C7.2, EPD_C8.2, EPD_C9.2, EPD_C10.2, EPD_C11.2, EPD_C12.2, IC1.2 (VSS), IC3.3 (GND), J1.A1, J1.A12, J1.B1, J1.B12, J1.MP1, J1.MP2, J1.MP3, J1.MP4, J2.G1 (GND_1), J2.G2 (GND_2), J2.G3 (GND_3), J2.G4 (GND_4), J2.P6 (VSS), J3.8, J3.17, J3.MP1, J3.MP2, J4.1, R1_PWRUSB.1, R2-USB1.1, R2-USB2.2, R2_BAT.1, R4.2, R5.1, RESET_BUTTON.1, RESET_BUTTON.2, SJ1.1, TP4.TP, TP5.TP, U1.2 (VSS), U2.1 (GND), U2.28 (GND), U2.29_1 (GND), U2.29_2 (GND), U2.29_3 (GND), U2.29_4 (GND), U2.29_5 (GND), U2.29_6 (GND), U2.29_7 (GND), U2.29_8 (GND), U2.29_9 (GND), U3.1 (GND), U3.5 (SDO), U3.7 (GND), U4.1 (CTG), U4.4 (GND), U4.6 (QSTRT), U4.9 (EP), U5.13 (GND), U6.4 (GND), U6.9 (EXP)
GPIO8: R7.1, U2.10 (IO8)
I2C_PW: C1.1, C2.1, R9.2, R10.2, U2.17 (IO19), U3.2 (CSB), U3.6 (VDDIO), U3.8 (VDD)
INT_RTC: R1_PINH1.1, TP15.TP, U2.8 (IO0), U5.3 (SQW/!INT)
IO/BOOT: BOOT_BUTTON.3, BOOT_BUTTON.4, COND_BOOT.1, R_BOOT.1, U2.15 (IO9)
IO/CHANGE: CHANGE_BUTTON.3, CHANGE_BUTTON.4, COND_CHANGE.1, R_CHANGE.1, U2.23 (IO15)
MISO: D7.2, J2.P7 (DAT0), R11.1, TP6.TP, U2.27 (IO2), U6.2 (DO(IO1))
MOSI: D8.2, J2.P3 (CMD), J3.14, R12.1, TP7.TP, U2.7 (IO7), U6.5 (DI(IO0))
unnamed: C1_BAT1.1, D2.1 (CATHODE), IC1.1 (VIN), IC1.3 (CE), Q1.2 (S)
unnamed: EPD_C12.1, J3.24
unnamed: R1_BAT.2, U1.1 (STAT)
unnamed: J1.B5, R2-USB2.1
unnamed: J1.A5, R2-USB1.2
unnamed: C5_USB4.1, D3.1 (K), D4.2 (A)
unnamed: LED1.C, R1_BAT.1
unnamed: R2_BAT.2, U1.5 (PROG)
unnamed: D6.1 (CATHODE), R_CAPACITOR.2
unnamed: EPD_C10.1, J3.22
unnamed: C_DELAY.1, IC3.5 (CT)
unnamed: EPD_C7.1, J3.19
unnamed: EPD_C8.1, J3.20
unnamed: EPD_C6.1, J3.18
unnamed: EPD_C2.1, J3.5
unnamed: EPD_C1.1, J3.4
PREVGH: D5.1 (K), EPD_C9.1, J3.21
PREVGL: D3.2 (A), EPD_C11.1, J3.23
RESE: J3.3, Q2.2 (S), R6.2
RESE': R4.1, R6.1, SJ1.2
RESET: COND_RESET.1, IC3.1 (VOUT), RESET_BUTTON.3, RESET_BUTTON.4, R_RESET.1, U2.3 (EN)
RTC_RST: U2.16 (IO18), U5.4 (!RST)
RX: TP2.TP, U2.24 (RXD0/GPIO17)
SCK: D9.2, J2.P5 (CLK), J3.13, R13.1, TP8.TP, U2.6 (IO6), U6.6 (CLK)
SCL: J4.4, U2.20 (IO22), U3.4 (SCK), U4.7 (SCL), U5.16 (SCL)
SDA: J4.3, R9.1, R10.1, U2.19 (IO21), U3.3 (SDI), U4.8 (SDA), U5.15 (SDA)
SRC: C5_USB4.2, D5.2 (A), L1.1, Q2.3 (D)
SS_SD: D12.2, J2.P2 (CD/DAT3), R16.1, U2.4 (IO4)
TX: TP1.TP, U2.25 (TXD0/GPIO16)
USB_D+: D1.1 (I/O1_1), U2.14 (IO13)
USB_D-: D1.3 (I/O2_1), U2.13 (IO12)
VBAT: C2_BAT.1, Q1.3 (D), TP3.TP, U1.3 (VBAT), U4.2 (CELL), U4.3 (VDD)
VBUS: C1_BAT.1, C4_USB.1, C5_USB.1, D1.5 (VBUS), D2.2 (ANODE), LED1.A, PFMF.050.1.2, Q1.1 (G), R1_PWRUSB.2, TP14.TP, U1.4 (VIN)
VRTC: C7.2, C8.1, R_CAPACITOR.1, U5.14 (VBAT)
VUSB: J1.A4, J1.A9, J1.B4, J1.B9, PFMF.050.1.1

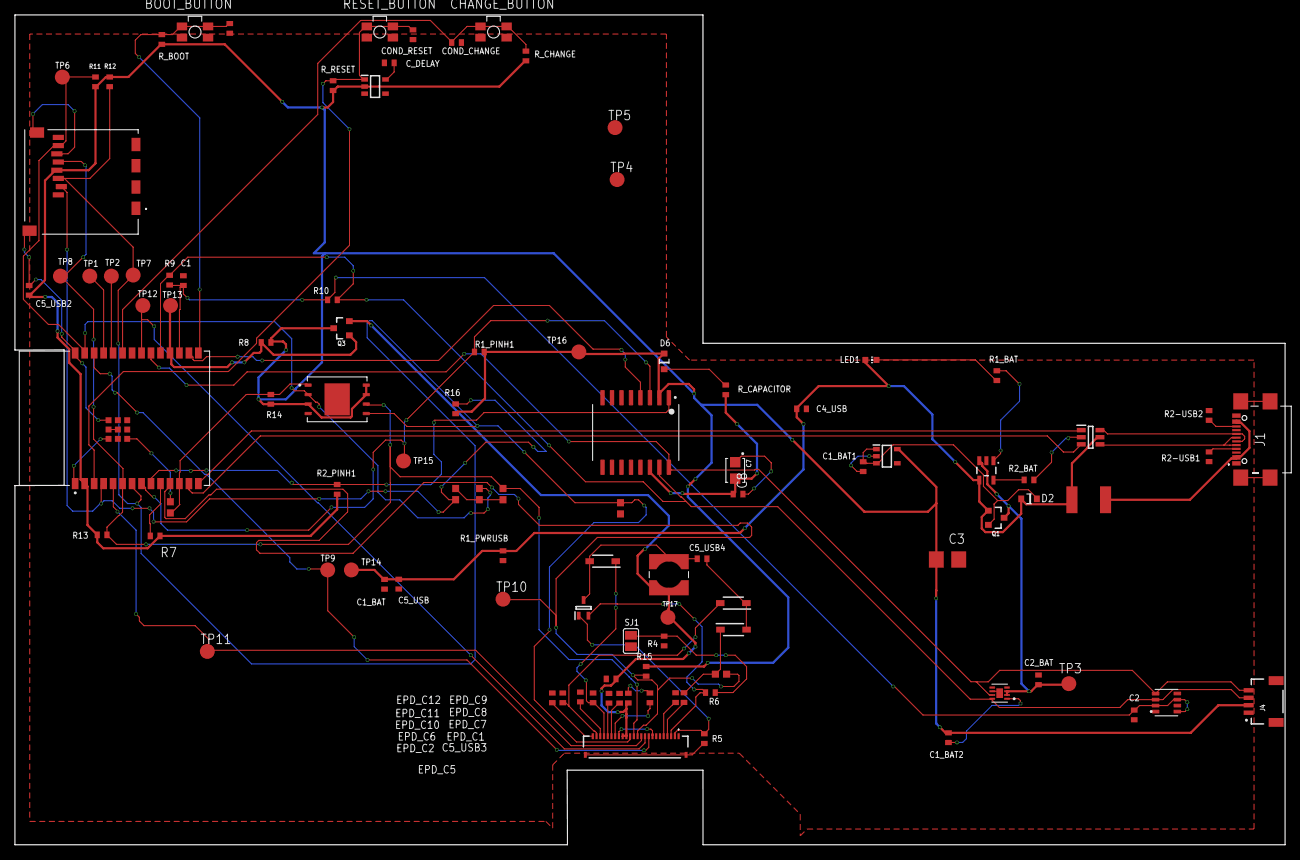
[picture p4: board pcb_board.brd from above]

Board: 2 copper layers, 170.2 x 111.2 mm, 103 parts (0 on the bottom side), 55 nets.

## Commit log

2025-04-05 add project
    [Pick-and-Place.csv, bill-of-materials.csv, pcb_board.brd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]
2025-04-14 Resolve Issue 1 2 and add battery cable
    [pcb_board.brd, schematic.sch]

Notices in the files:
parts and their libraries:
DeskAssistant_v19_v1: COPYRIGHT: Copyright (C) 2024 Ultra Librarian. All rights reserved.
